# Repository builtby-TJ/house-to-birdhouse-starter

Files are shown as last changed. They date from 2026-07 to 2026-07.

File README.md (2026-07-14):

# House-to-Birdhouse Web App — Starter Repository

This repository is the starting implementation for a web application that converts guided house photographs into a six-part, 3D-printable birdhouse kit:

1. Front wall
2. Back wall
3. Left wall
4. Right wall
5. Roof
6. Floor

The intended production output is a multi-plate 3MF project for Bambu Studio, plus individual STEP/STL files, browser-preview geometry, an assembly guide, and a validation report.

## What is working in this starter

- Version 1 product and mechanical specifications
- Locked #4 x 1/2-inch stainless self-tapping screw standard
- Machine-readable mechanical configuration
- JSON Schema for house-project data
- Pydantic project models
- FastAPI project/API scaffold
- Executable prototype geometry generator
- Sample six-part STL and GLB generation
- Automated tests for schema and output structure
- A handoff roadmap for developers

The executable geometry generator is an early prototype, not the final manufacturing CAD kernel. It proves the data flow and six-part output. The production milestone replaces/extends it with CadQuery/OpenCascade solids, true bores, rabbets, STEP export, and tolerance-controlled mating features.

## Run locally

Requires Python 3.11+.

```bash
cd services/cad_engine
python -m venv .venv
source .venv/bin/activate        # Windows: .venv\\Scripts\\activate
pip install -e '.[dev,production-cad]'

birdhouse-cad generate ../../sample_projects/basic_colonial.json --output ../../generated/basic_colonial
birdhouse-cad validate ../../sample_projects/basic_colonial.json
birdhouse-cad generate-coupons --output ../../generated/test_coupons
birdhouse-cad generate-blank-shell ../../sample_projects/basic_colonial.json --output ../../generated/production_blank_shell
birdhouse-cad generate-production ../../sample_projects/basic_colonial.json --output ../../generated/production_model
```

Production CAD is pinned to CadQuery 2.8.0 and cadquery-ocp/OpenCascade
7.9.3.1.1. The test-coupon command reads all screw and joint dimensions from
`config/mechanical_standard.yaml` and writes verified STEP and STL exports.
The generated set includes screw-fit, corner-joint, raised-lip base-to-wall, and
underside-rib roof-to-header assembly coupons. These remain physically unvalidated until the selected supplier
screw and printed fits are measured.

The blank-shell command generates six CadQuery/OpenCascade solids with STEP and
STL exports, the locked 24-screw layout, floor lips, roof ribs, and true bores.
It remains physically unvalidated and is not labeled print-ready.
The production command adds JSON-defined normalized windows, doors, shutters,
trim, color-group metadata, and the optional functional entrance opening.
Its delivery package includes six STEP/STL pairs, project JSON, exploded GLB,
multi-object 3MF, validation report, hardware list, and assembly instructions.

Start the API:

```bash
uvicorn birdhouse_cad.api:app --reload --port 8000
```

Then open:

- `http://localhost:8000/docs`
- `http://localhost:8000/health`

## Initial API workflow

```text
POST /v1/projects/validate
POST /v1/models/generate
GET  /v1/models/{job_id}
GET  /v1/models/{job_id}/manifest
```

Projects, revisions, and generation jobs persist in SQLite by default under
`generated_jobs/`. Configure `BIRDHOUSE_DATABASE_PATH` and `BIRDHOUSE_OUTPUT_ROOT`
for deployment storage. PostgreSQL and a durable distributed worker remain deployment work.

The operator web workspace supports four facade photo sets, draggable normalized
features, exact feature dimensions, measurement calibration, revision saves, CAD
generation, and the guided eight-view capture checklist. The vision diagnostic API
checks resolution, exposure, likely blur, and duplicates; it reports whether COLMAP
is installed without ever treating reconstruction output as a print mesh.

## Repository map

```text
apps/web/                    Next.js customer/operator UI scaffold
config/                      Mechanical and printer standards
docs/                        Product specification and handoff plan
sample_projects/             Known-good house inputs
schemas/                     Shared JSON schemas
services/cad_engine/         Python CAD/API service
infrastructure/              Docker Compose and deployment notes
```

## First production objective

Generate a physically validated six-part birdhouse from structured facade measurements before adding automated photogrammetry. The photo pipeline should populate the same project schema rather than bypass the parametric manufacturing engine.

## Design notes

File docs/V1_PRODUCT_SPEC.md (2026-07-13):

# Version 1 Product Specification

## Goal

Accept guided photographs and corrected facade data for a residential house, then generate six independently printable parts that assemble into a recognizable birdhouse using one standardized screw type.

## Supported house geometry

- One rectangular main footprint
- One or two stories represented as a single facade height
- Front, back, left, and right facade panels
- Gable roof in the first production release
- Rectangular doors and windows
- Shallow facade relief for trim, shutters, siding, brick, and foundation
- Optional functional bird entrance opening

## Deferred geometry

- Curved walls
- Freeform roof surfaces
- Multiple attached wings
- Full decks, complex railings, and landscaping
- Automatic reconstruction of every decorative object
- Direct unattended printing

## Customer workflow

1. Create a project.
2. Identify the front of the house.
3. Capture at least two photographs of each side plus corner transition photographs.
4. Enter one known measurement.
5. Review corrected front, back, left, and right elevations.
6. Confirm doors, windows, roof type, entrance-hole location, and colors.
7. Preview the assembled and exploded model.
8. Generate and download the print package.

## Output package

- Multi-plate 3MF project
- Front, back, left, right, roof, and floor files
- STEP and STL where supported
- GLB browser preview
- Project JSON
- Validation report
- Assembly instructions
- Hardware list

## Acceptance standard

The system is commercially useful when an operator can correct four facade elevations and the software automatically creates six printable, physically fitting parts without manual CAD editing.

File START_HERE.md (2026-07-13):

# Start Here

## Can this be built for the owner?

Yes. The owner does not need to write the application personally. Development can proceed in this project as a sequence of reviewed code checkpoints, with outside specialists used only where access, physical testing, deployment credentials, or specialized CAD review is required.

## Division of responsibility

### Work that can be produced inside this project

- Product specifications and decision records
- Repository architecture
- Backend and frontend source code
- Parametric CAD scripts
- Data schemas and API contracts
- Automated tests
- Docker configuration
- Sample projects
- Validation logic
- Developer tickets and acceptance criteria
- Handoff packages and code-review guidance

### Work requiring owner or external access

- Purchasing and measuring the exact production screw
- Running physical prints on the target printer
- Confirming fit, finish, assembly force, and outdoor durability
- Creating and paying for cloud/vendor accounts
- Supplying deployment secrets and domain access
- App-store publishing if a native app is later chosen
- Professional security/legal review before public customer use

Those external actions do not require the owner to become a programmer. They can be performed by a contractor, printing service, or designated technical operator using the specifications in this repository.

## What has already been built

The starter contains an executable prototype that:

1. Validates a structured house-project JSON file.
2. Generates front, back, left, and right walls.
3. Generates a simplified gable roof and floor.
4. Adds facade relief features and prototype reinforced screw zones.
5. Exports six STL files.
6. Exports an exploded GLB preview.
7. Writes a machine-readable manifest.
8. Exposes a FastAPI validation/generation API.
9. Runs automated schema and output tests.

## Next implementation checkpoint

The next coding checkpoint is **Production CAD Milestone 1**:

- Install and pin CadQuery/OpenCascade.
- Rebuild one corner joint as a true CAD solid.
- Add true clearance bore, pilot bore, and counterbore geometry.
- Generate a printable corner coupon and screw-boss coupon.
- Export STEP and STL.
- Add dimensional assertions to automated tests.

## Exact first physical action

Select and purchase the intended #4 x 1/2-inch stainless self-tapping pan-head screw. Record:

- Manufacturer
- Part number
- Thread type
- Head diameter
- Head height
- Overall length
- Actual major thread diameter

The current dimensions are appropriate starting values, but the final counterbore must be generated from the selected supplier's screw measurements.

## Handoff instruction

Give a developer the complete repository and instruct them to read, in order:

1. `START_HERE.md`
2. `docs/V1_PRODUCT_SPEC.md`
3. `docs/3MF_Birdhouse_Fastener_Memory.md`
4. `config/mechanical_standard.yaml`
5. `docs/HANDOFF_BUILD_PLAN.md`
6. `docs/CURRENT_STATUS.md`

Their first pull request should complete Production CAD Milestone 1 without changing the locked six-part architecture or fastener standard.

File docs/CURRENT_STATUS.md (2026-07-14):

# Current Build Status

## Completed software milestones

- Reproducible CadQuery/OpenCascade container image
- Parametric screw-fit, corner, base, and roof assembly coupons
- JSON-driven six-part production CAD kernel
- True pilot holes, clearance holes, counterbores, floor lips, and roof ribs
- Normalized facade windows, doors, shutters, trim, color groups, and entrance opening
- STEP, STL, exploded GLB, and multi-object 3MF delivery package
- Validation report, hardware list, project JSON, and assembly instructions
- Persistent revisioned projects and generation jobs
- Interactive four-facade operator editor
- Guided eight-view photo capture checklist
- Resolution, exposure, blur, duplicate, and COLMAP-availability diagnostics
- Automated backend, export, API, web, and container validation

## Ready to test

The application is ready for local operator-workflow and software-output testing.
Generated production CAD remains marked `production_cad_unvalidated_physically`.

## External blockers to print-ready certification

- Select and purchase the exact #4 x 1/2-inch stainless self-tapping pan-head screw.
- Record its supplier, part number, head diameter, head height, thread diameter, and actual length.
- Print the coupons and record pilot, rabbet, lip, and rib fit results.
- Feed confirmed measurements and fit compensation back into the mechanical standard.
- Print and assemble a complete reference house.

## Deployment work not required for local product testing

- PostgreSQL adapter and migration strategy
- S3-compatible object storage
- Redis-backed distributed workers and retries
- Authentication, authorization, retention controls, and audit-log policy
- Hosted COLMAP worker and representative customer photo corpus
- Payment/order workflow and production operations dashboard

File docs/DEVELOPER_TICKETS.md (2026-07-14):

# Developer Ticket Queue

## CAD-001 — Production CAD environment — COMPLETE

Create a reproducible Python 3.11 container with pinned CadQuery/OpenCascade dependencies. Add a smoke test that exports a valid STEP cube and STL cube.

**Acceptance criteria**

- Container builds from a clean machine.
- STEP and STL exports are non-empty.
- Dependency versions are documented and pinned.

## CAD-002 — Screw coupon — COMPLETE, PHYSICAL VALIDATION OPEN

Generate a configurable coupon containing pilot holes of 2.1, 2.2, and 2.3 mm plus counterbores based on the selected physical screw.

**Acceptance criteria**

- Dimensions come from `mechanical_standard.yaml`.
- Hole labels are embossed or engraved.
- STEP and STL export successfully.

## CAD-003 — Corner assembly coupon — COMPLETE, PHYSICAL VALIDATION OPEN

Generate two wall segments with a stepped rabbet alignment joint and two screw positions.

**Acceptance criteria**

- Parts self-locate at 90 degrees.
- Clearance holes are in the first part.
- Pilot holes are in the receiving part.
- Screw tips cannot protrude into the interior.
- Automated assembly alignment test passes.

## CAD-004 — Base assembly coupon — COMPLETE, PHYSICAL VALIDATION OPEN

Generate a floor segment and wall segment using the raised locating lip and two upward screws.

## CAD-005 — Roof assembly coupon — COMPLETE, PHYSICAL VALIDATION OPEN

Generate a wall header and roof segment using an underside locating rib and two downward screws.

## CAD-006 — Complete blank shell — COMPLETE, PHYSICAL VALIDATION OPEN

Generate four blank walls, roof, and floor from structured dimensions. No facade decorations are required yet.

## CAD-007 — Facade feature system — COMPLETE, PHYSICAL VALIDATION OPEN

Add parametric windows, doors, trim, shutters, and material/color groups using normalized coordinates.

## API-001 — Persistent project model — LOCAL PROFILE COMPLETE

Replace the development job registry with PostgreSQL-backed projects, revisions, files, and jobs.

## UI-001 — Operator facade editor — COMPLETE FOR LOCAL TESTING

Create four facade workspaces supporting photo placement and draggable normalized rectangles for doors and windows.

## CAPTURE-001 — Guided photo checklist — COMPLETE FOR LOCAL TESTING

Create the front/right/back/left mobile capture sequence with required and optional shots.

## VISION-001 — COLMAP diagnostic worker — IMAGE DIAGNOSTICS COMPLETE, HOSTED COLMAP OPEN

Accept project images and return camera-registration statistics, sparse cloud, and a diagnostic preview. Do not create the final print mesh from the raw reconstruction.

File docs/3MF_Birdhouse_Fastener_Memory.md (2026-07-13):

# Project Memory — Screw and Fastener Standard for 3MF Birdhouse Kit

## Purpose

This document records the locked screw/fastener decision for the 3D-printed six-piece birdhouse kit. It should be kept with the project files so future modeling, 3MF exports, assembly instructions, and hardware sourcing all use the same fastener standard.

## Product Context

The birdhouse will be produced as a ready-to-assemble kit, not as a fully assembled product. The box should include:

- 6 separately printed 3MF house parts
- 24 screws, plus a few extras
- a small included screwdriver
- printed/photo assembly instructions
- packaging suitable for a premium real-estate closing gift

The finished product is intended to function as an outdoor birdhouse, so the fastener system should be simple for the customer while still being suitable for long-term exterior exposure.

## Six-Part 3MF Assembly

The model should be designed as six separate printable parts from the beginning:

1. Base plate / floor
2. Front wall panel
3. Back wall panel
4. Left wall panel
5. Right wall panel
6. Roof assembly

The model should not be designed as one solid 3D model and then split apart afterward. Each part should include its own mating geometry, screw pockets, alignment features, and reinforced screw-receiving areas.

## Locked Fastener Direction

Use self-tapping screws directly into printed plastic.

Heat-set brass inserts are not being used for this version because they add tooling, installation time, and customer complexity. The goal is for the recipient to assemble the birdhouse with a simple included hand screwdriver.

## Locked Screw Standard

Use:

**#4 stainless steel self-tapping pan-head screws**

Preferred general specification:

- Size: #4
- Length: 1/2 inch
- Material: stainless steel
- Head style: pan head
- Drive style: Phillips or Torx
- Quantity: 24 screws total
- Extras: include 2–4 spare screws in the kit
- Tool: include the matching small screwdriver or driver bit

Preferred default:

**#4 × 1/2 in stainless steel self-tapping pan-head screw**

## Why Pan Head Instead of Countersunk Flat Head

The preferred design is a pan-head screw seated inside a counterbored pocket, not a flat-head screw seated in a conical countersink.

Reason:

- A pan-head screw clamps against a flat surface.
- A counterbored recess can hide the screw head while avoiding wedge pressure.
- A countersunk flat-head screw can create splitting or stress in printed plastic if overtightened.
- A counterbored pan-head pocket is more forgiving for a non-technical customer assembling the kit by hand.

The screw should sit flush or slightly below the exterior surface, but the recess should be a flat-bottom counterbore rather than a conical countersink unless future testing proves countersunk screws are acceptable.

## Wall and Boss Thickness Standard

Recommended geometry for the 3MF files:

| Area | Target Thickness |
|---|---:|
| General exterior wall panels | 4.0 mm |
| Base plate | 5.0–6.0 mm |
| Roof shell | 4.0–5.0 mm |
| Wall bottom sill receiving zone | 8.0–10.0 mm |
| Wall top header receiving zone | 8.0–10.0 mm |
| Vertical corner screw-receiving zone | 8.0–10.0 mm |
| Local screw boss outside diameter | 8.0–10.0 mm minimum |

The screw should not rely on a plain thin wall for holding strength. Every screw location should have a reinforced boss, rib, sill, header, or thickened receiving area.

## Hole Geometry Starting Point

Use the following as the starting geometry unless a specific screw supplier provides different dimensions:

| Feature | Recommended Starting Geometry |
|---|---:|
| Pilot hole into receiving plastic | 2.2 mm |
| Acceptable pilot-hole range | 2.1–2.3 mm |
| Clearance hole through first part | 3.0–3.2 mm |
| Counterbore diameter for screw head | 5.8–6.2 mm |
| Counterbore depth | 1.8–2.2 mm, or enough for chosen screw head |
| Minimum plastic around pilot hole | 3.0 mm radial minimum |
| Minimum screw-center distance from outside edge | 5.5–6.5 mm minimum |
| Target screw engagement into receiving plastic | approximately 6–8 mm |

The final counterbore diameter and depth should be checked against the actual #4 screw selected for sourcing, because pan-head diameter and height vary by manufacturer.

## Screw Layout

Total screws: **24**

### Base Plate to Wall Sill Plates — 8 Screws

- 2 screws per wall
- Screws pass upward from the base plate into the bottom sill of each wall panel
- Screw heads are recessed into the underside or lower surface of the base plate
- Wall panels need reinforced lower sill receiving zones

### Corner Wall-to-Wall Joints — 8 Screws

- 2 screws per corner
- 4 corners total
- Screws pass through the face of one wall panel into the edge of the adjacent wall panel
- Each corner should include lap, rabbet, or alignment geometry so screws clamp the joint but do not provide all alignment

### Roof to Wall Header Plates — 8 Screws

- 2 screws per wall
- Screws pass downward through the roof assembly into the top header of each wall panel
- Screw heads are recessed into the roof surface
- Each wall panel needs a reinforced top header receiving zone

## Alignment Features Required

The screws should clamp the parts together, but alignment should come from the printed geometry.

Include:

- Base plate groove or raised alignment lip
- Wall bottom tabs or sill features
- Rabbet or lap-style vertical corner joints
- Roof underside locating ribs
- Reinforced screw bosses
- Clear assembly orientation features so the customer cannot easily reverse parts

## Customer Assembly Notes

The kit should be designed so the customer uses one screw type and one included screwdriver.

Instructions should say:

- Do not overtighten.
- Tighten until the screw head is seated and the parts are snug.
- Stop when the screw is flush or slightly below the recessed pocket.
- Do not keep turning after resistance increases sharply.
- Assemble on a flat table.
- Confirm all wall panels are seated in the base before tightening roof screws.

The hardware bag should include:

- 24 required #4 stainless self-tapping screws
- 2–4 spare screws
- 1 small matching screwdriver or driver bit

## Outdoor Use Notes

Because the birdhouse is intended for outdoor use:

- Use stainless steel screws, not plain steel.
- Avoid black oxide screws for exterior use.
- Avoid zinc-plated screws if long-term weather exposure is a major goal.
- Keep screw tips from protruding into the bird cavity.
- Avoid sharp internal edges.
- Include drainage holes in the base.
- Include ventilation under the roof/eaves.
- Prefer PETG, ASA, or another outdoor-suitable filament over PLA for final outdoor use.

## Current Locked Decision

The project should proceed using:

**#4 × 1/2 in stainless steel self-tapping pan-head screws, seated in recessed counterbored pockets, with 4.0 mm nominal wall panels and 8.0–10.0 mm reinforced screw-receiving zones.**

This decision should be treated as the fastener standard for all six 3MF files unless intentionally revised later.

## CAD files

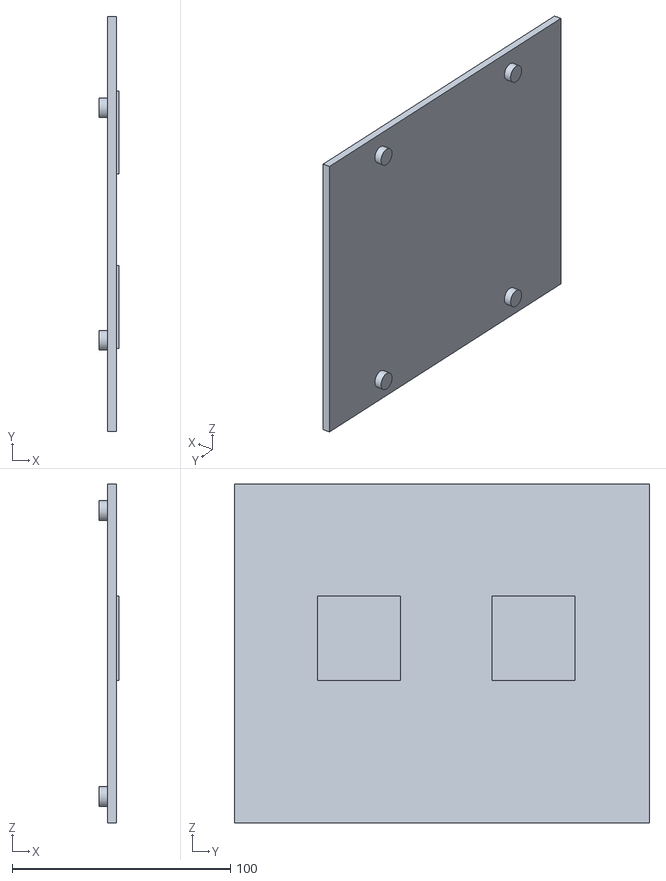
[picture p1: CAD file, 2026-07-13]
generated/basic_colonial/left_wall.stl
9.20 x 190.0 x 155.0

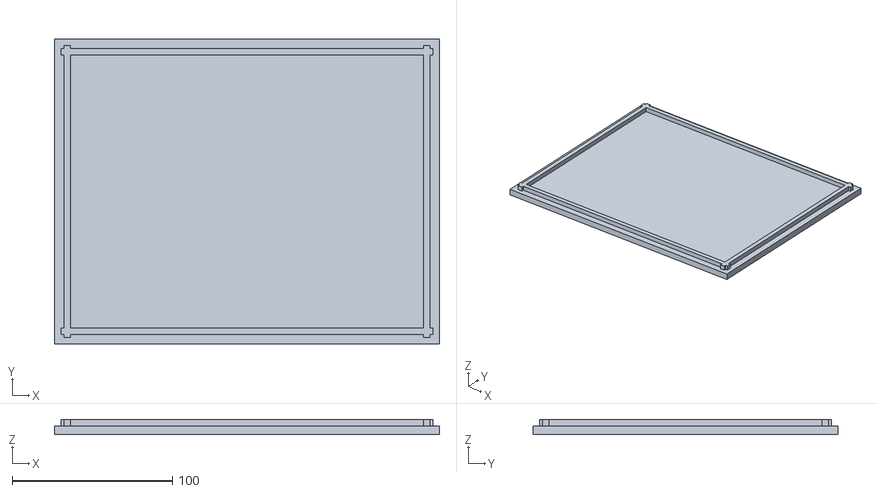
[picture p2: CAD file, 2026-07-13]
generated/basic_colonial/floor.stl
240.0 x 190.0 x 9.50

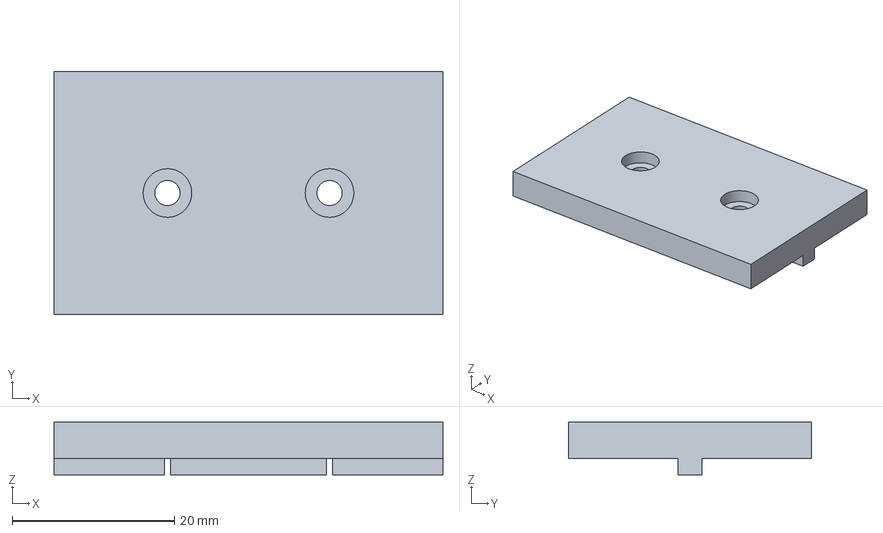
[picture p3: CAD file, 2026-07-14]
generated/test_coupons/roof_panel_part.step
48.0 x 30.0 x 6.50 mm

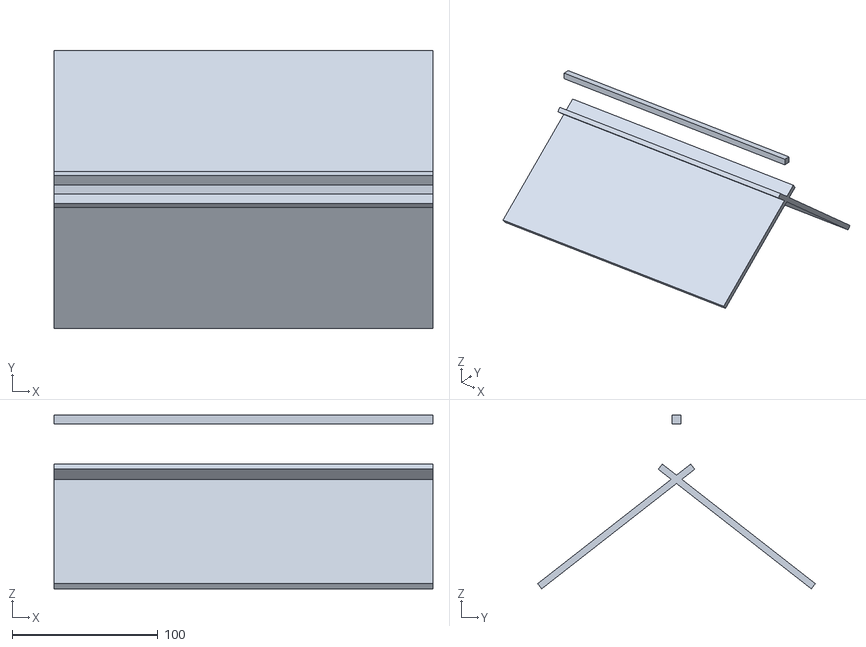
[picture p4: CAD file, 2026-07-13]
generated/basic_colonial/roof.stl
260.0 x 190.5 x 119.1

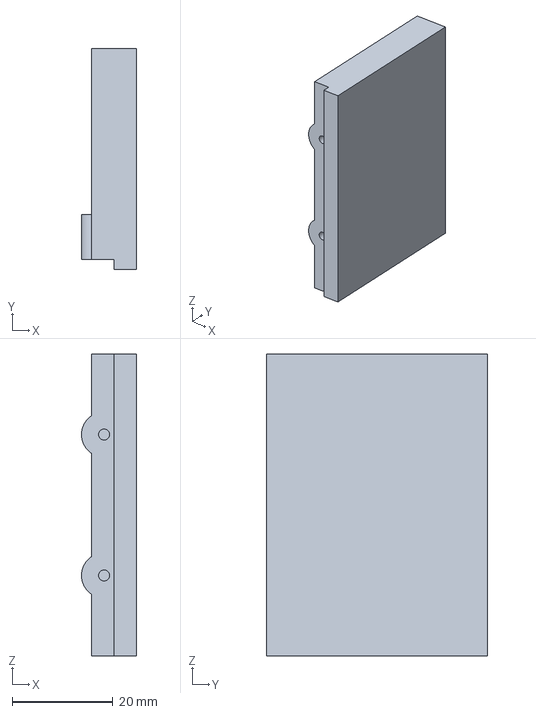
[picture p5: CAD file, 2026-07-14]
generated/test_coupons/corner_receiving_part.step
11.0 x 44.0 x 60.0 mm

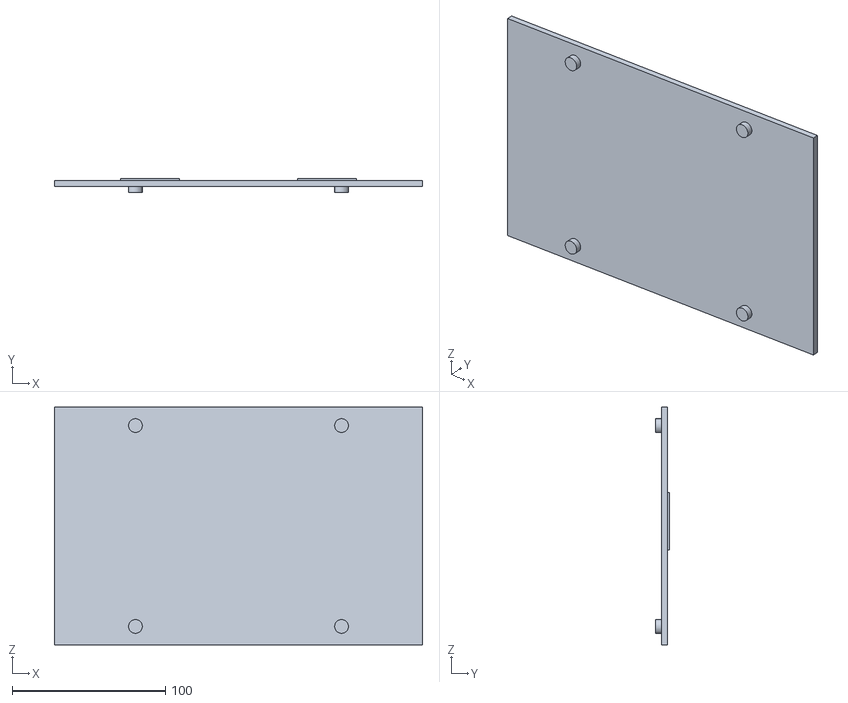
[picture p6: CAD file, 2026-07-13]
generated/basic_colonial/back_wall.stl
240.0 x 9.20 x 155.0

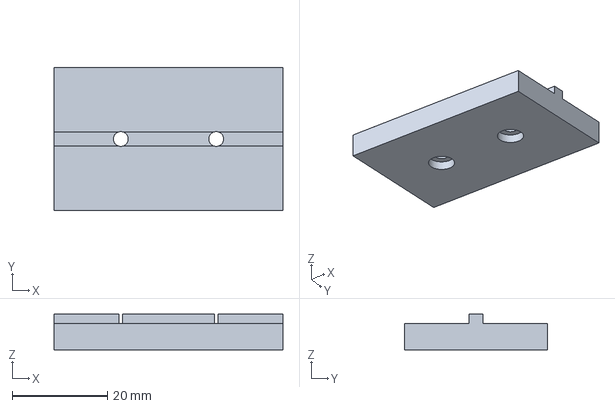
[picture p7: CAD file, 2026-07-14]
generated/test_coupons/base_floor_part.step
48.0 x 30.0 x 7.50 mm

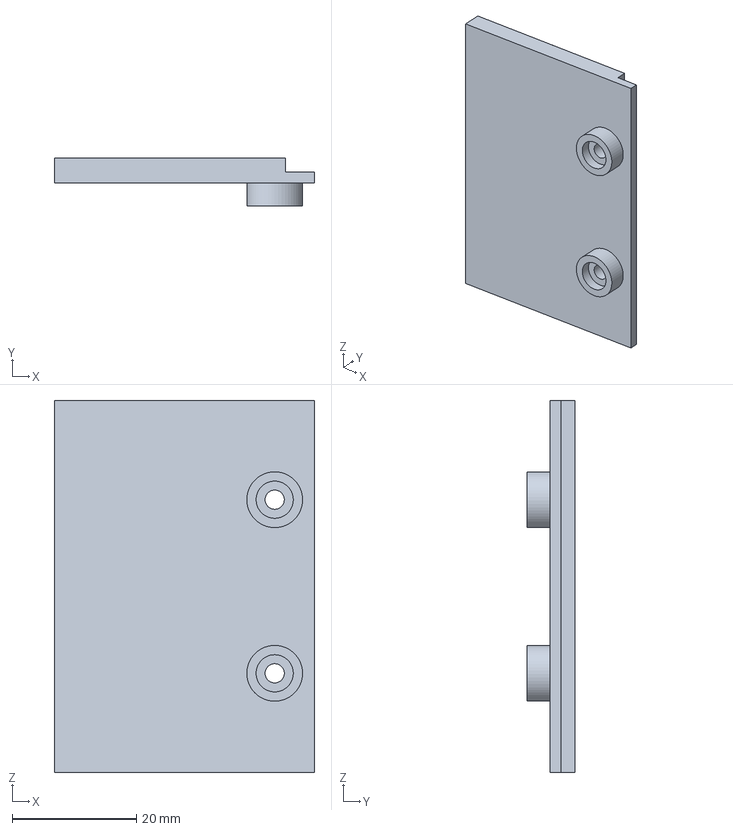
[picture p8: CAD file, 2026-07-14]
generated/test_coupons/corner_clearance_part.step
42.0 x 7.70 x 60.0 mm

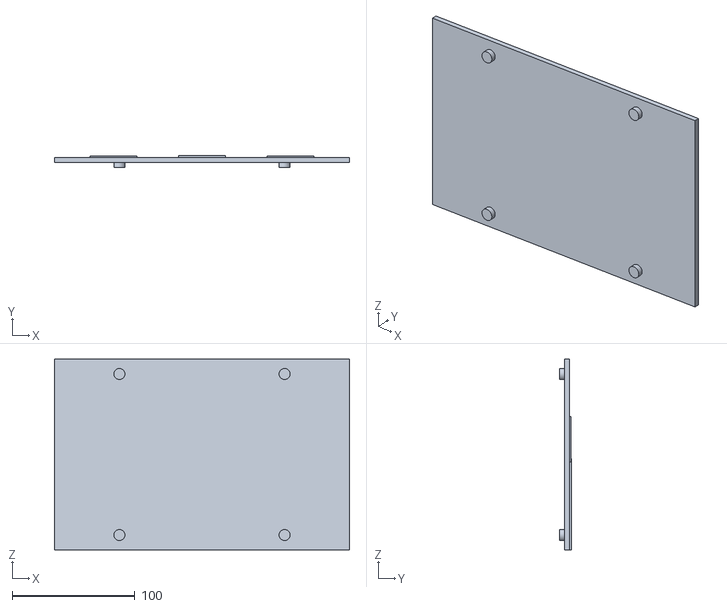
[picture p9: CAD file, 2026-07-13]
generated/basic_colonial/front_wall.stl
240.0 x 9.40 x 155.0

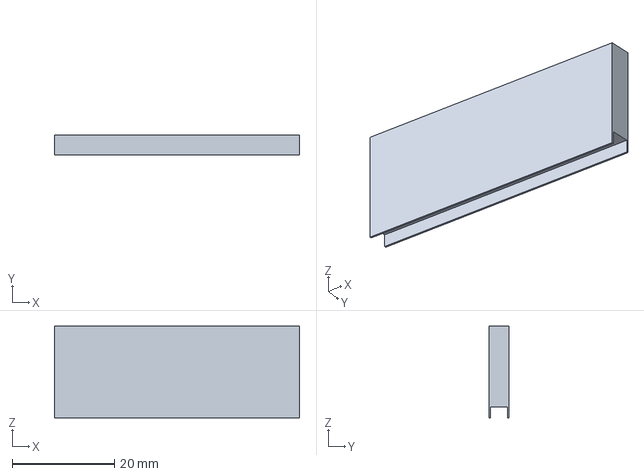
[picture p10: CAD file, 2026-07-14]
generated/test_coupons/base_wall_part.step
48.0 x 4.00 x 18.0 mm

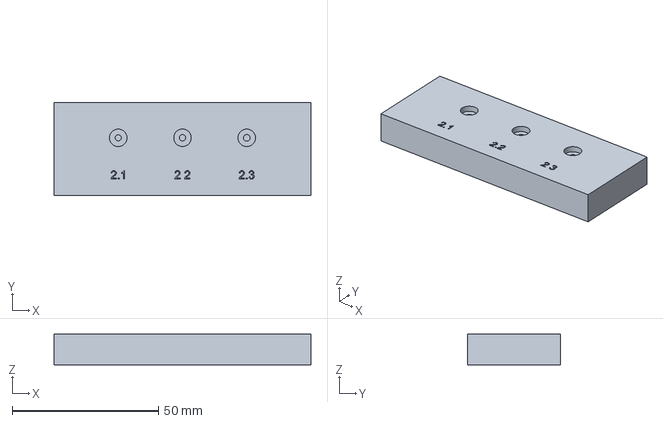
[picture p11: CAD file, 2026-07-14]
generated/test_coupons/screw_test_coupon.step
88.0 x 32.0 x 10.5 mm

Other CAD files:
generated/test_coupons/roof_header_part.step
generated/test_coupons/base_floor_part.stl
generated/test_coupons/base_wall_part.stl
generated/test_coupons/corner_clearance_part.stl
generated/test_coupons/corner_receiving_part.stl
generated/test_coupons/roof_header_part.stl
generated/test_coupons/roof_panel_part.stl
generated/test_coupons/screw_test_coupon.stl

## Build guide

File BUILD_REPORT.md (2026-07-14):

# Starter Build Report

Date: 2026-07-13

## Verification performed

- Installed the Python package in editable mode.
- Ran the automated test suite.
- Validated the included sample project.
- Generated all six prototype STL files.
- Generated an exploded GLB preview.
- Confirmed the six reported meshes are watertight according to Trimesh.

## Test result

```text
3 passed
```

## Generated sample files

- `generated/basic_colonial/front_wall.stl`
- `generated/basic_colonial/back_wall.stl`
- `generated/basic_colonial/left_wall.stl`
- `generated/basic_colonial/right_wall.stl`
- `generated/basic_colonial/roof.stl`
- `generated/basic_colonial/floor.stl`
- `generated/basic_colonial/exploded_preview.glb`
- `generated/basic_colonial/manifest.json`

## Important limitation

The current output is a working software prototype demonstrating the six-part pipeline. It is not yet approved for physical production because true pilot bores, counterbores, rabbet tolerances, roof locating ribs, and final screw engagement must be implemented and physically validated in the production CAD milestone.

## Production CAD Milestone 1 update

The `production-cad-milestone-1` branch adds CadQuery/OpenCascade test geometry without replacing the six-part prototype generator:

- A parametric screw coupon with 2.1, 2.2, and 2.3 mm blind pilot bores, flat-bottom 6.0 x 2.0 mm counterbores, and engraved labels.
- A two-piece 90-degree corner coupon with a 0.2 mm-clearance stepped rabbet, two 3.1 mm clearance bores, two 2.2 mm pilot bores, and 2.0 mm modeled screw-tip safety.
- A two-piece base assembly coupon with a raised locating lip, clearance-matched wall groove, and two upward screw stations.
- A two-piece roof assembly coupon with an underside locating rib, clearance-matched header groove, and two downward screw stations.
- STEP round-trip, STL watertightness, solid validity, dimensional, and assembly-alignment assertions.

Verification result: `6 passed`. The original sample also continues to generate six watertight reported meshes and its exploded GLB preview.

CAD-006 adds a JSON-driven six-part CadQuery blank shell with four walls, a gable
roof, and a raised-lip floor. It exports STEP and watertight STL files while retaining
the explicit physically-unvalidated production status.

CAD-007 adds normalized facade reliefs and color-group metadata to the production
wall solids, plus the optional functional entrance opening from the shared schema.

API-001 now has persistent, revisioned projects and generation-job records using a
local SQLite deployment profile. The storage boundary is isolated for a later
PostgreSQL adapter; distributed workers and object storage remain deployment work.

UI-001 and CAPTURE-001 now provide an interactive four-facade editor and guided
eight-view capture checklist. VISION-001 has a diagnostic-only image quality endpoint
and an explicit COLMAP availability boundary; COLMAP is not installed in this environment.

The coupon manifest intentionally reports `production_cad_test_coupons_unvalidated_physically`. The selected screw supplier dimensions have not been confirmed, and no physical fit/print test has been performed. Docker is not available in the verification environment, so the updated container smoke test could not be executed here.

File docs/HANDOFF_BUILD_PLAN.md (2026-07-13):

# Build and Handoff Plan

## Ownership model

The owner does not need to become the primary programmer. This repository is intended to be handed to a computational-CAD developer and a full-stack developer. The owner remains product decision-maker, supplies representative house photographs, approves simplification rules, and validates printed results.

## Workstream 1 — Manufacturing CAD engine

Primary owner: computational CAD developer.

Deliverables:

- Parametric wall solids
- Gable roof generator
- Floor generator
- Rabbet/lap corner joints
- Base locating lip or groove
- Roof locating ribs
- True screw clearance holes, pilot holes, counterbores, and reinforced bosses
- Door/window/trim relief generators
- STEP, STL, GLB, and 3MF-compatible exports
- Assembly collision and alignment tests

Definition of done:

- Six parts generate from JSON.
- All are valid closed solids.
- Screw centers align.
- Parts fit the printer profile.
- Printed reference assembly fits using the specified screws.

## Workstream 2 — Operator facade editor

Primary owner: full-stack developer with browser-graphics experience.

Deliverables:

- Photo upload and side labeling
- Perspective-correction controls
- Normalized facade coordinate system
- Add, move, resize, duplicate, and delete architectural features
- Known-dimension calibration
- Color/material grouping
- Three-dimensional assembled and exploded previews

## Workstream 3 — Guided photo capture

Deliverables:

- Mobile-friendly progressive web app
- Required shot checklist
- Blur, exposure, duplication, and resolution checks
- House-side and corner labeling
- Retake guidance
- Upload resume and progress state

## Workstream 4 — Reconstruction and vision assistance

Primary owner: computer-vision engineer.

Deliverables:

- COLMAP camera reconstruction
- Sparse/dense geometry diagnostics
- Major wall-plane estimation
- Facade rectification
- Building/obstruction segmentation
- Suggested windows, doors, rooflines, and wall outlines
- Confidence scores and review queue

The vision output must populate the shared project schema. It must not directly create uncontrolled print meshes.

## Workstream 5 — Production platform

Deliverables:

- Authentication
- PostgreSQL project database
- S3-compatible file storage
- Redis/message broker
- Durable workers
- Revisioned project files
- Job retries and error states
- Audit logs
- Data retention/deletion controls
- Operator dashboard

## Recommended hiring order

1. Computational CAD developer
2. Full-stack developer
3. Computer-vision engineer
4. Part-time product/UI designer
5. 3D-print/mechanical QA support

## Suggested paid CAD trial

Ask a candidate to implement one JSON-driven test project containing:

- Four parametric walls
- One gable roof
- One floor
- Alignment joints
- Twenty-four standardized screw locations
- One door and four windows
- Six STL files and one STEP assembly

Evaluate geometric correctness, code organization, tolerance awareness, reproducibility, and ease of changing dimensions.

## Milestones

### M0 — Specification lock

- Confirm actual screw supplier/part number.
- Measure its head diameter and height.
- Approve V1 house limitations.
- Approve target birdhouse dimensions.

### M1 — Six-part CAD proof

- Structured JSON to six solids
- Physical print and screw assembly
- Basic validation report

### M2 — Manual operator product

- Upload four-side photographs
- Trace/correct facades
- Generate downloadable print package

### M3 — Guided customer capture

- Mobile photo workflow
- Quality checks
- Measurement calibration

### M4 — Automated assistance

- Camera reconstruction
- Rectified elevations
- Suggested architectural features

### M5 — Pilot operations

- Payment/order workflow if required
- Operator review queue
- Production logging
- Controlled customer pilot

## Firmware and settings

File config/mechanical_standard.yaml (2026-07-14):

product:
  name: house_birdhouse_v1
  units: mm
  parts:
    - front_wall
    - back_wall
    - left_wall
    - right_wall
    - roof
    - floor

material:
  preferred: ASA
  alternatives:
    - PETG
  prototype_allowed:
    - PLA

panels:
  nominal_wall_thickness: 4.0
  minimum_wall_thickness: 3.2
  floor_thickness: 5.5
  roof_thickness: 4.5
  bottom_sill_thickness: 9.0
  top_header_thickness: 9.0
  corner_receiving_zone: 9.0

screws:
  designation: "#4 x 1/2 in"
  length_mm: 12.7
  type: self_tapping
  material: stainless_steel
  head: pan
  drive: phillips_or_torx
  required_quantity: 24
  spare_quantity: 4
  pilot_hole_diameter: 2.2
  pilot_hole_range: [2.1, 2.3]
  clearance_hole_diameter: 3.1
  counterbore_diameter: 6.0
  counterbore_depth: 2.0
  boss_outside_diameter: 9.0
  target_engagement: 7.0
  minimum_edge_distance: 6.0
  supplier_measurements_confirmed: false

test_coupons:
  screw_coupon:
    body_depth: 32.0
    station_spacing: 22.0
    bottom_safety_thickness: 1.5
    label_engraving_depth: 0.6
  corner_coupon:
    segment_length: 42.0
    segment_height: 60.0
    rabbet_depth: 2.0
    rabbet_width: 4.5
    fit_clearance: 0.2
    screw_heights: [16.0, 44.0]
  base_coupon:
    segment_length: 48.0
    floor_depth: 30.0
    wall_height: 18.0
    lip_width: 3.0
    lip_height: 2.0
    fit_clearance: 0.2
    screw_positions: [14.0, 34.0]
  roof_coupon:
    segment_length: 48.0
    roof_depth: 30.0
    header_height: 18.0
    rib_width: 3.0
    rib_height: 2.0
    fit_clearance: 0.2
    screw_positions: [14.0, 34.0]

assembly:
  base_to_wall_screws: 8
  wall_corner_screws: 8
  roof_to_wall_screws: 8
  corner_joint: stepped_rabbet
  base_alignment: raised_perimeter_lip
  roof_alignment: underside_locating_ribs

printer_profiles:
  bambu_h2d_conservative:
    max_part_x: 300.0
    max_part_y: 300.0
    max_part_z: 300.0

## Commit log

2026-07-13 Baseline imported starter repository
    [back_wall.stl, floor.stl, front_wall.stl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]
2026-07-14 Add production CAD test coupons and container smoke workflow
    [corner_clearance_part.step, corner_clearance_part.stl, corner_receiving_part.step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]
2026-07-14 Add base assembly CAD coupon
    [base_floor_part.step, base_floor_part.stl, base_wall_part.step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]
2026-07-14 Build production CAD and operator workflow
    [base_floor_part.step, base_wall_part.step, corner_clearance_part.step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]
